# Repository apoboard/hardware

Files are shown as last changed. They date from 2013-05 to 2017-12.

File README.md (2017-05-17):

hardware
========

This Repo contains EAGLE CAD files for the DIY Interactive Electronics Apogaea PCB.

2013-14 Sound-reactive Sheriff Star
=======================================
<p align="center">

</p>

The system is based on an Atmega328p microcontroller (the same device in the Arduino Uno) and can be programmed with an FTDI serial adapter and the Arduino IDE. There is a DC/DC boost-converter to provide 5 volts from a single AA battery to a microphone, amplifier, and 3 RGB LEDs that are driven from common PWM channels. There is also a momentary tactile button for user input.

2017 Propagand-Eye
=======================================
<p align="center">

</p>

This board uses an Atmega328p microcontroller (the same device in the Arduino Uno) and can be programmed with an FTDI serial adapter and the Arduino IDE. There is a DC/DC boost-converter (the PAM2401) to provide 5 volts from a single AA battery. On board are 10 addressable WS2812 LEDs (the same LEDs used on all Neopixel products). There is also an infrared (IR) transmitter/receiver pair that allows the boards to communicate with one another. A tactile button is also provided to switch through modes.

License Information
-------------------

All of these files are developed for free, for Apogaea, and for fun. It is publicly available under the GNU General Public License version 2 (the "GPL License"). For more information, please see: http://www.gnu.org/licenses/gpl-2.0.html

Copyright (c) John English, Joel Bartlett, 2017 Licensing: GPL v2

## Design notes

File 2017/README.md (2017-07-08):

2017 Propagand-Eye
=======================================
<p align="center">

</p>

This board uses an Atmega328p microcontroller (the same device in the Arduino Uno) and can be programmed with an FTDI serial adapter and the Arduino IDE. There is a DC/DC boost-converter (the PAM2401) to provide 5 volts from a single AA battery. On board are 10 addressable WS2812 LEDs (the same LEDs used on all Neopixel products). There is also an infrared (IR) transmitter/receiver pair that allows the boards to communicate with one another. A tactile button is also provided to switch through modes.

Hacking Your Eyeball
=======================================
This section will cover all the information you'll need to start hacking your eye via hardware.

Arduino IDE Settings
----------------------
* Arduino IDE Version - 1.6.8
* Board - Arduino Uno
* Baud Rate - 115200

Hardware Pin connections
------------------
* Button Pin - D2
* WS2812 LED Pin - D7
* IR_RX Pin - D8
* IR_TX Pin - D9

Assembly Instructions
-------------------
<p align="center">

</p>

See the [Software README](https://github.com/apoboard/software/blob/master/2017/README.md) for more info. 

License Information
-------------------

All of these files are developed for free, for Apogaea, and for fun. It is publicly available under the GNU General Public License version 2 (the "GPL License"). For more information, please see: http://www.gnu.org/licenses/gpl-2.0.html

Copyright (c) John English, Joel Bartlett, 2017 Licensing: GPL v2

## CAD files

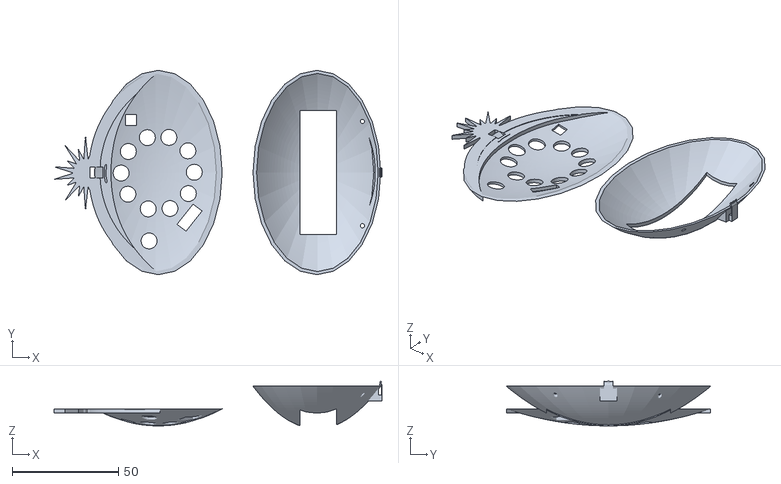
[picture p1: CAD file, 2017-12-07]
2017/3D Files/PropogandEye case.stl
154.1 x 96.0 x 21.0

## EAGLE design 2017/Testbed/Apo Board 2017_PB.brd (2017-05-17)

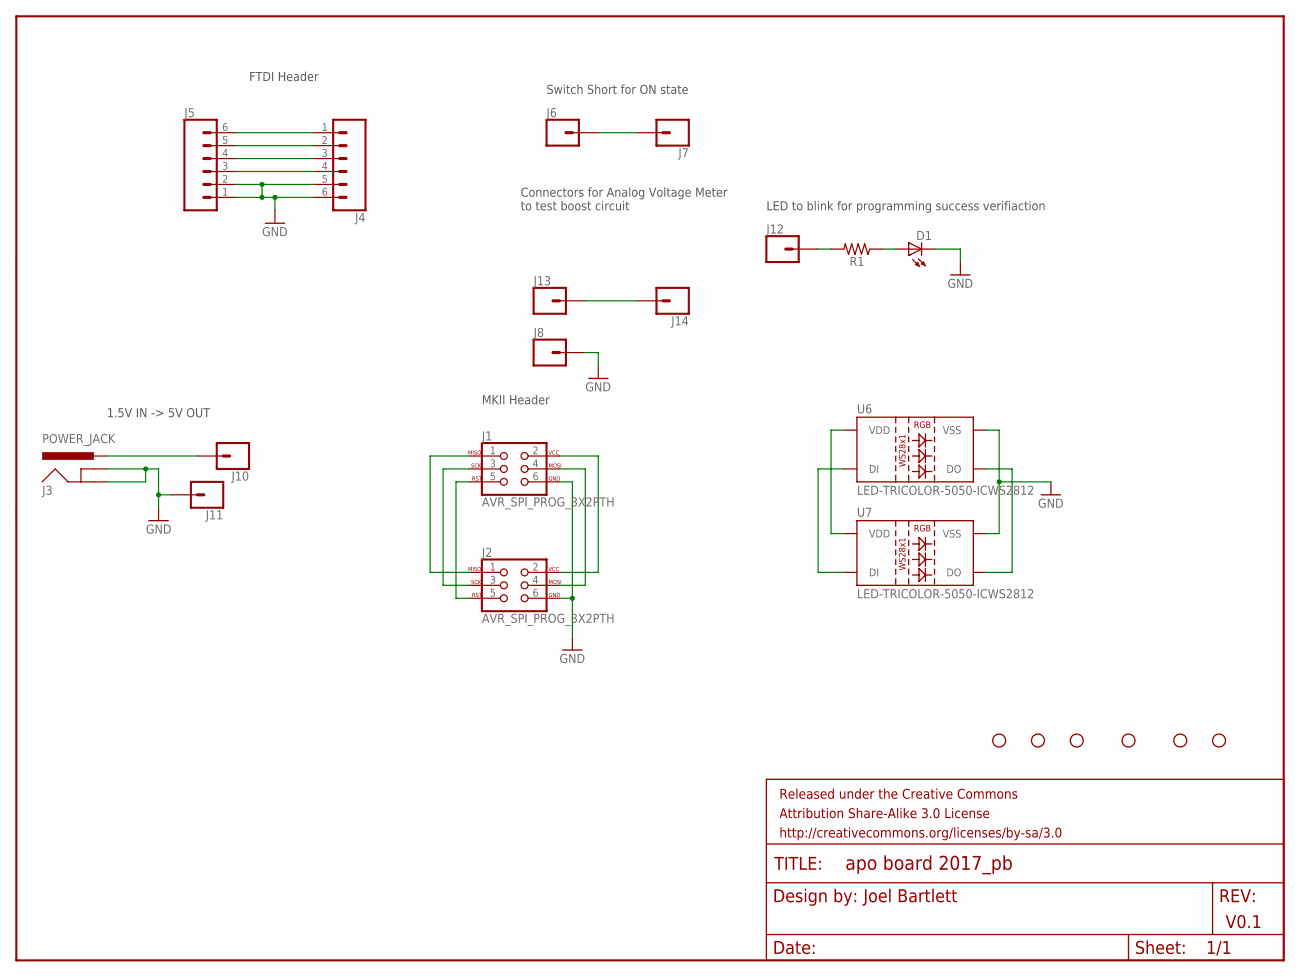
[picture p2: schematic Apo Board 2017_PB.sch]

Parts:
D1: LED5MM
FRAME1: FRAME-LETTER; CREATIVE_COMMONS
H1, H2, H3, H4, H5, H6: STAND-OFF
J1, J2: AVR_SPI_PROG_3X2PTH; 2X3
J3: POWER_JACK; POWER_JACK_PTH
J4, J5: CONN_06LONGPADS; 1X06_LONGPADS
J6, J7, J8, J10, J11, J12, J13, J14: CONN_01PTH_LONGPAD; 1X01_LONGPAD
R1: AXIAL-0.3-KIT
U6, U7: LED-TRICOLOR-5050-ICWS2812; LED-WS2812-THRU

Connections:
GND: D1.K (C), J1.6, J2.6, J3.GND, J3.GNDBREAK, J4.5, J4.6, J5.1, J5.2, J8.1, J11.1, U6.3 (VSS), U7.3 (VSS)
unnamed: J3.PWR, J10.1
unnamed: J1.4, J2.4
unnamed: J1.2, J2.2
unnamed: J1.5, J2.5
unnamed: J1.3, J2.3
unnamed: J1.1, J2.1
unnamed: U6.4 (DO), U7.4 (DO)
unnamed: J4.4, J5.3
unnamed: J4.3, J5.4
unnamed: J4.2, J5.5
unnamed: J4.1, J5.6
unnamed: J6.1, J7.1
unnamed: D1.A, R1.P$1 (1)
unnamed: J12.1, R1.P$2 (2)
unnamed: U6.1 (DI), U7.1 (DI)
unnamed: J13.1, J14.1
unnamed: U6.2 (VDD), U7.2 (VDD)

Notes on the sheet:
Joel Bartlett
V0.1
Switch Short for ON state
FTDI Header
1.5V IN -> 5V OUT
MKII Header
Connectors for Analog Voltage Meter to test boost circuit
LED to blink for programming success verifiaction

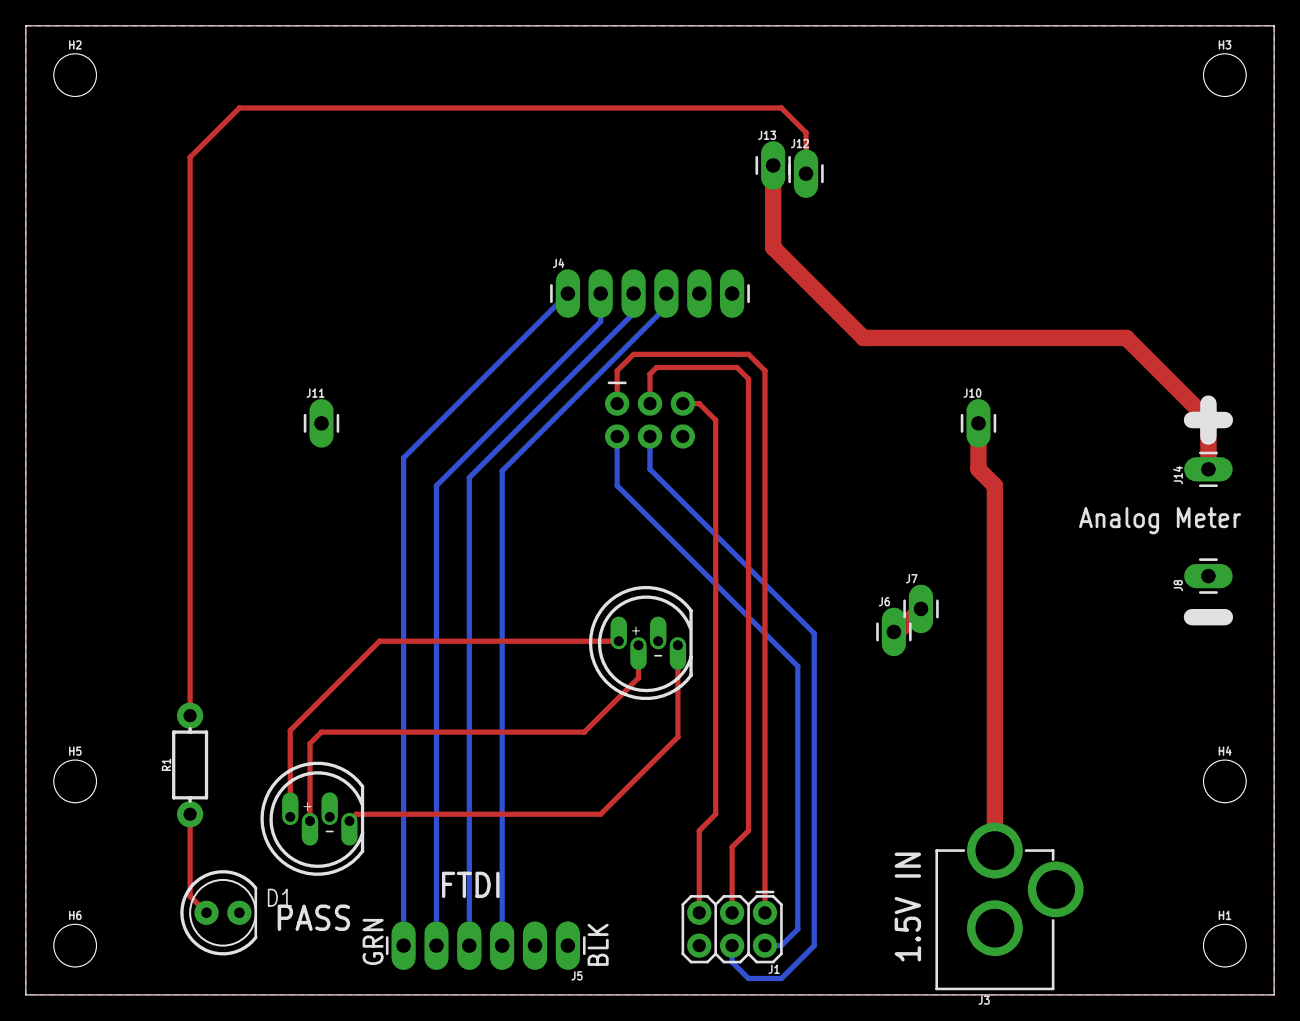
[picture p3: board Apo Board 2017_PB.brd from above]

Board: 2 copper layers, 96.5 x 74.9 mm, 24 parts (1 on the bottom side), 18 nets.

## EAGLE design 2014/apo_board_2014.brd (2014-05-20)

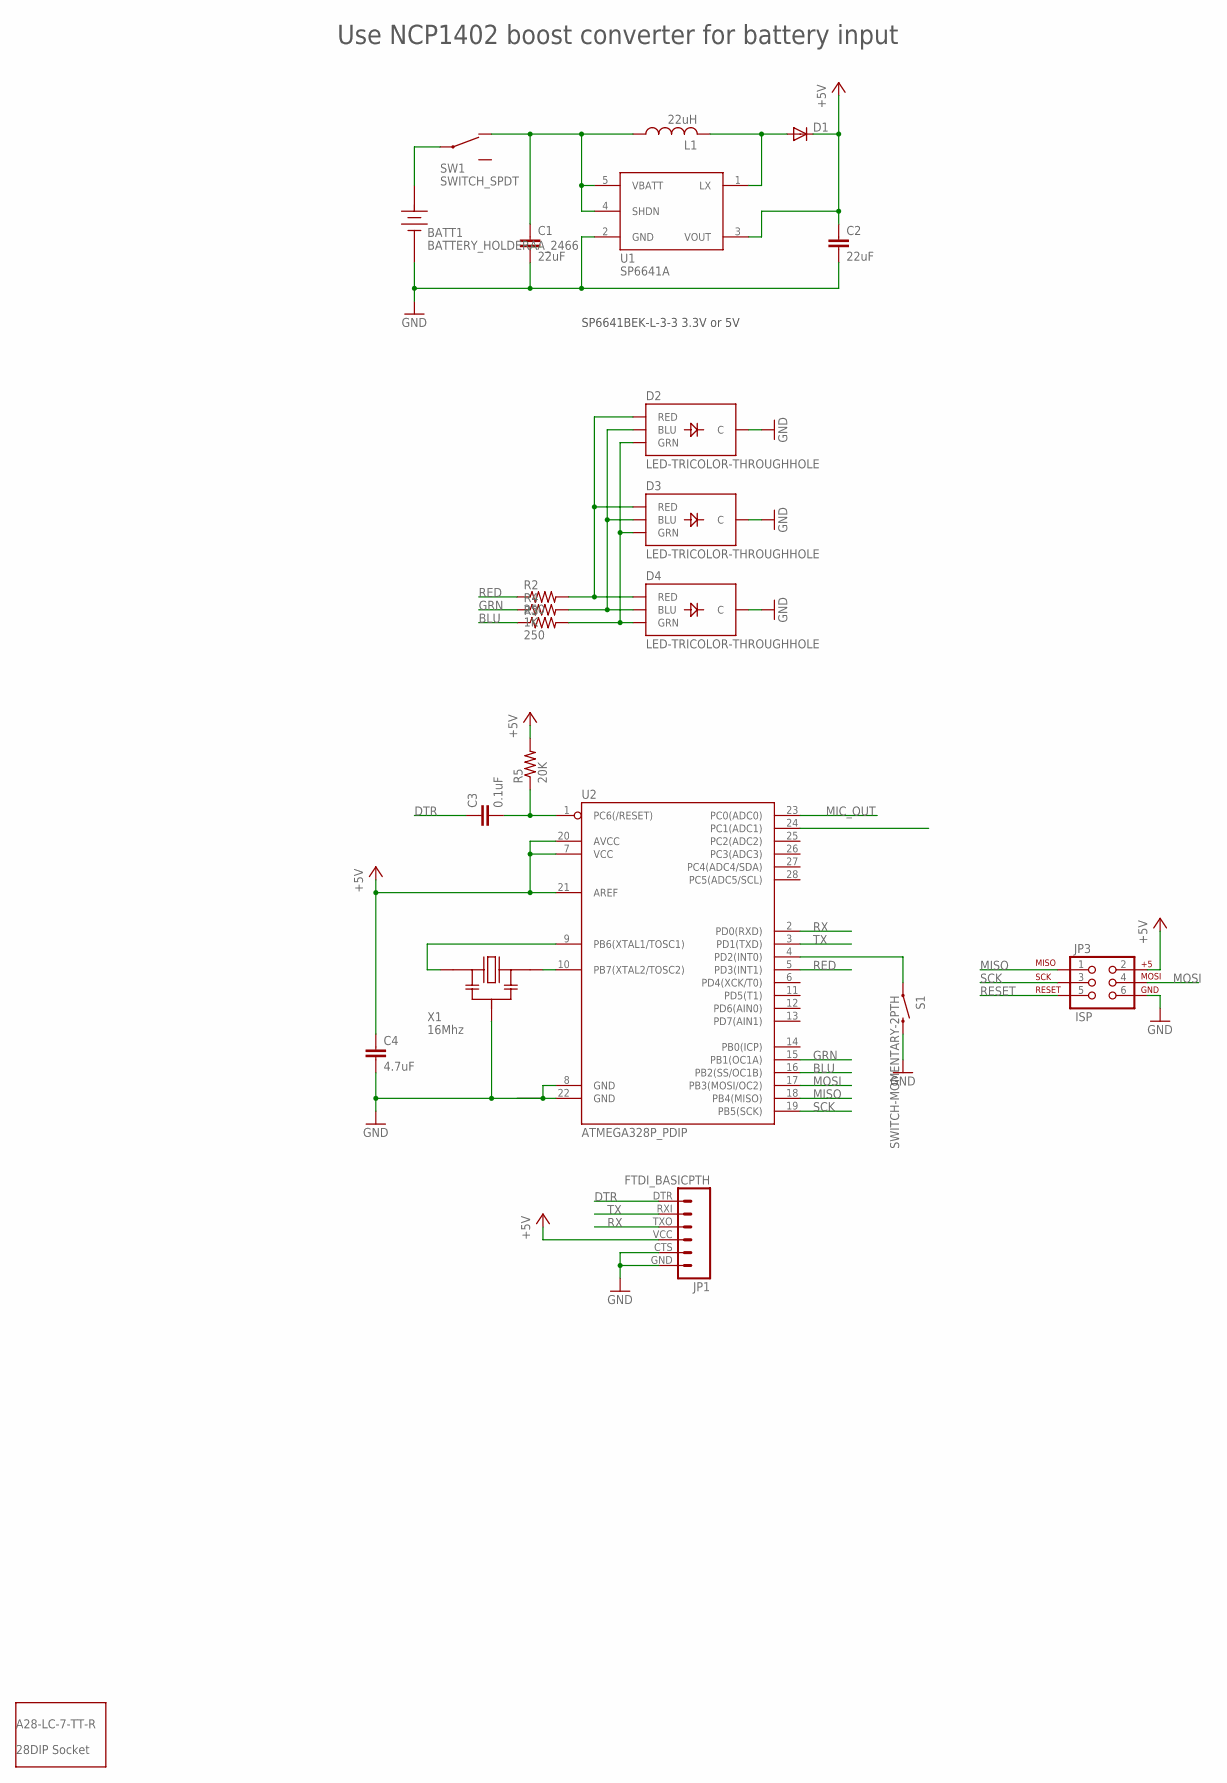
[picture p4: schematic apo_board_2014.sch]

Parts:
BATT1: BATTERY_HOLDERAA_2466; BATT_HOLDER_AA_2466
C1, C2: 22uF; CAP-PTH-SMALL-KIT
C3: 0.1uF; CAP-PTH-SMALL-KIT
C4: 4.7uF; CAP-PTH-SMALL-KIT
D1: DIODEKIT; DIODE-1N4148-KIT
D2, D3, D4: LED-TRICOLOR-THROUGHHOLE
JP1: FTDI_BASICPTH; FTDI_BASIC
JP3: ISP; 2X3
L1: 22uH; INDUCTOR_AIUR-02H
R2, R3: 250; AXIAL-0.3-KIT
R4: 1K; AXIAL-0.3-KIT
R5: 20K; AXIAL-0.3-KIT
S1: SWITCH-MOMENTARY-2PTH; TACTILE-PTH
SW1: SWITCH_SPDT; SWITCH_SPDT_OS102011MA1QN1C
U1: SP6641A; SOT23-5
U2: ATMEGA328P_PDIP; DIL28-3
X1: 16Mhz; CERAMIC_RESONATOR_ZTT

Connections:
+5V: C2.1, C4.1, D1.C, JP1.VCC (4), JP3.2, R5.P$2 (2), U1.3 (VOUT), U2.7 (VCC), U2.20 (AVCC), U2.21 (AREF)
BATT: BATT1.P, SW1.P$2 (COMMON)
BLU: R3.P$1 (1), U2.16 (PB2(SS/OC1B))
DTR: C3.1, JP1.DTR (1)
GND: BATT1.N, C1.2, C2.2, C4.2, D2.GND (C), D3.GND (C), D4.GND (C), JP1.CTS (5), JP1.GND (6), JP3.6, S1.3 (2), U1.2 (GND), U2.8 (GND), U2.22 (GND), X1.P$2
GRN: R4.P$1 (1), U2.15 (PB1(OC1A))
MIC_OUT: U2.23 (PC0(ADC0))
MISO: JP3.1, U2.18 (PB4(MISO))
MOSI: JP3.4, U2.17 (PB3(MOSI/OC2))
unnamed: U2.9 (PB6(XTAL1/TOSC1)), X1.P$1
unnamed: U2.10 (PB7(XTAL2/TOSC2)), X1.P$3
unnamed: S1.1, U2.4 (PD2(INT0))
unnamed: D2.GRN, D3.GRN, D4.GRN, R3.P$2 (2)
unnamed: D2.BLU, D3.BLU, D4.BLU, R4.P$2 (2)
unnamed: C3.2, R5.P$1 (1), U2.1 (PC6(/RESET))
unnamed: D2.RED, D3.RED, D4.RED, R2.P$2 (2)
unnamed: D1.A, L1.P$2 (2), U1.1 (LX)
unnamed: C1.1, L1.P$1 (1), SW1.P$3 (3), U1.4 (SHDN), U1.5 (VBATT)
RED: R2.P$1 (1), U2.5 (PD3(INT1))
RESET: JP3.5
RX: JP1.TXO (3), U2.2 (PD0(RXD))
SCK: JP3.3, U2.19 (PB5(SCK))
TX: JP1.RXI (2), U2.3 (PD1(TXD))

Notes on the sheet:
Use NCP1402 boost converter for battery input
SP6641BEK-L-3-3 3.3V or 5V

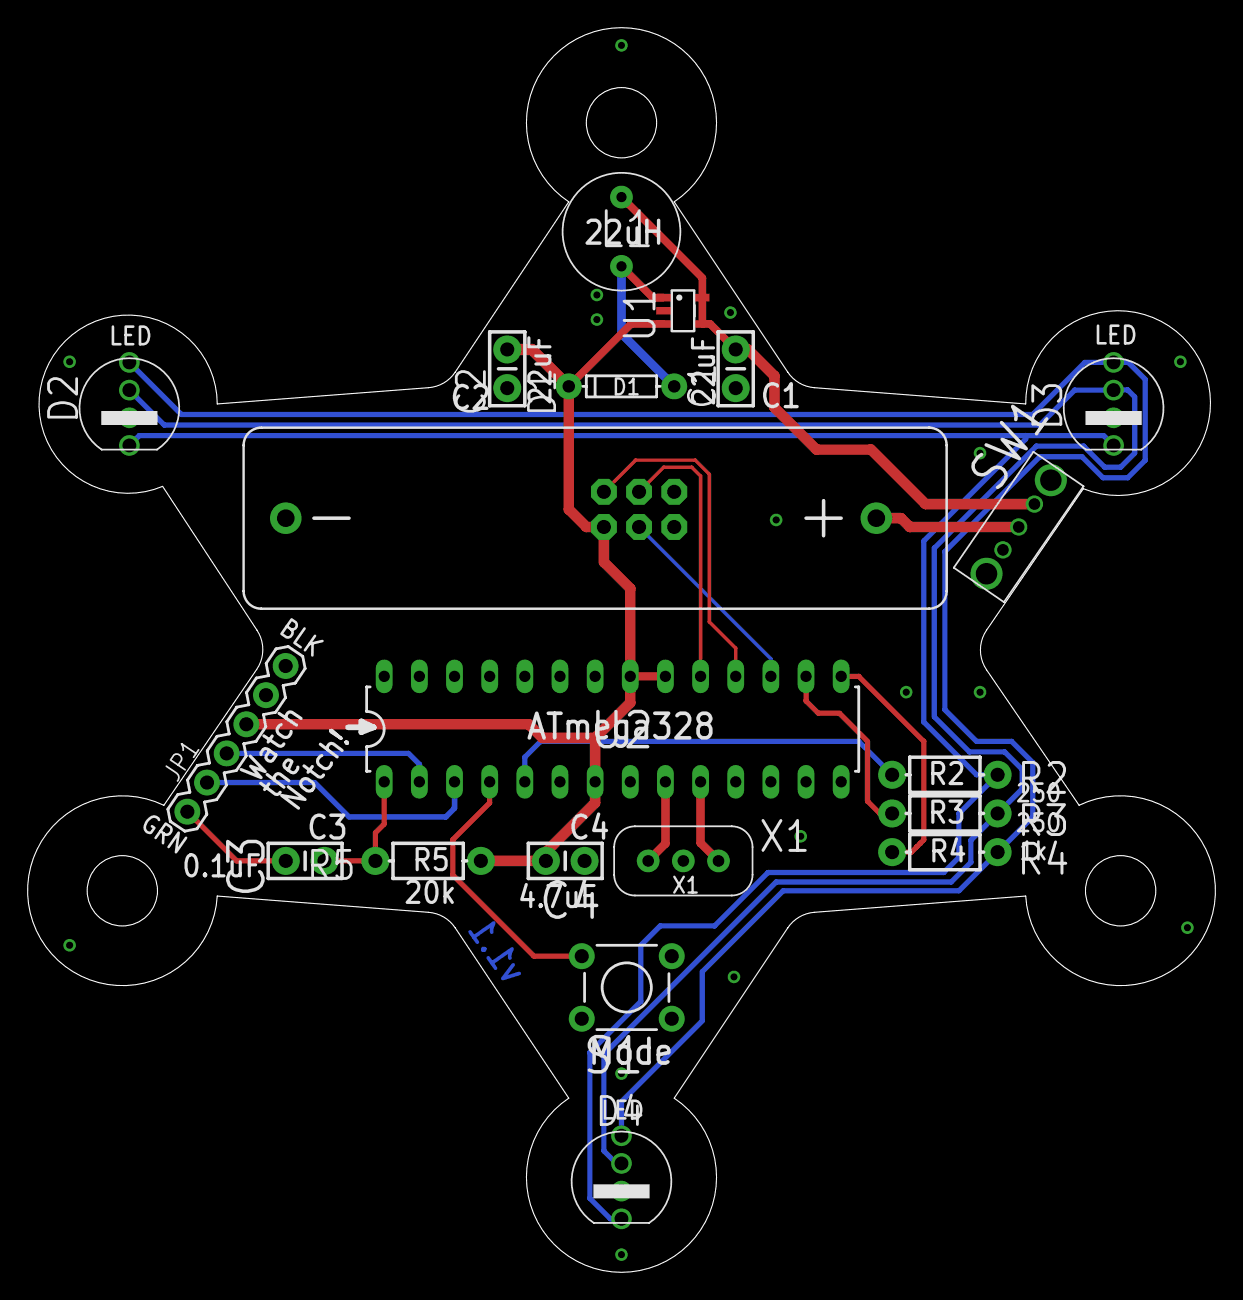
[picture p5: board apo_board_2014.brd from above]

Board: 2 copper layers, 85.8 x 89.9 mm, 21 parts (1 on the bottom side), 21 nets.

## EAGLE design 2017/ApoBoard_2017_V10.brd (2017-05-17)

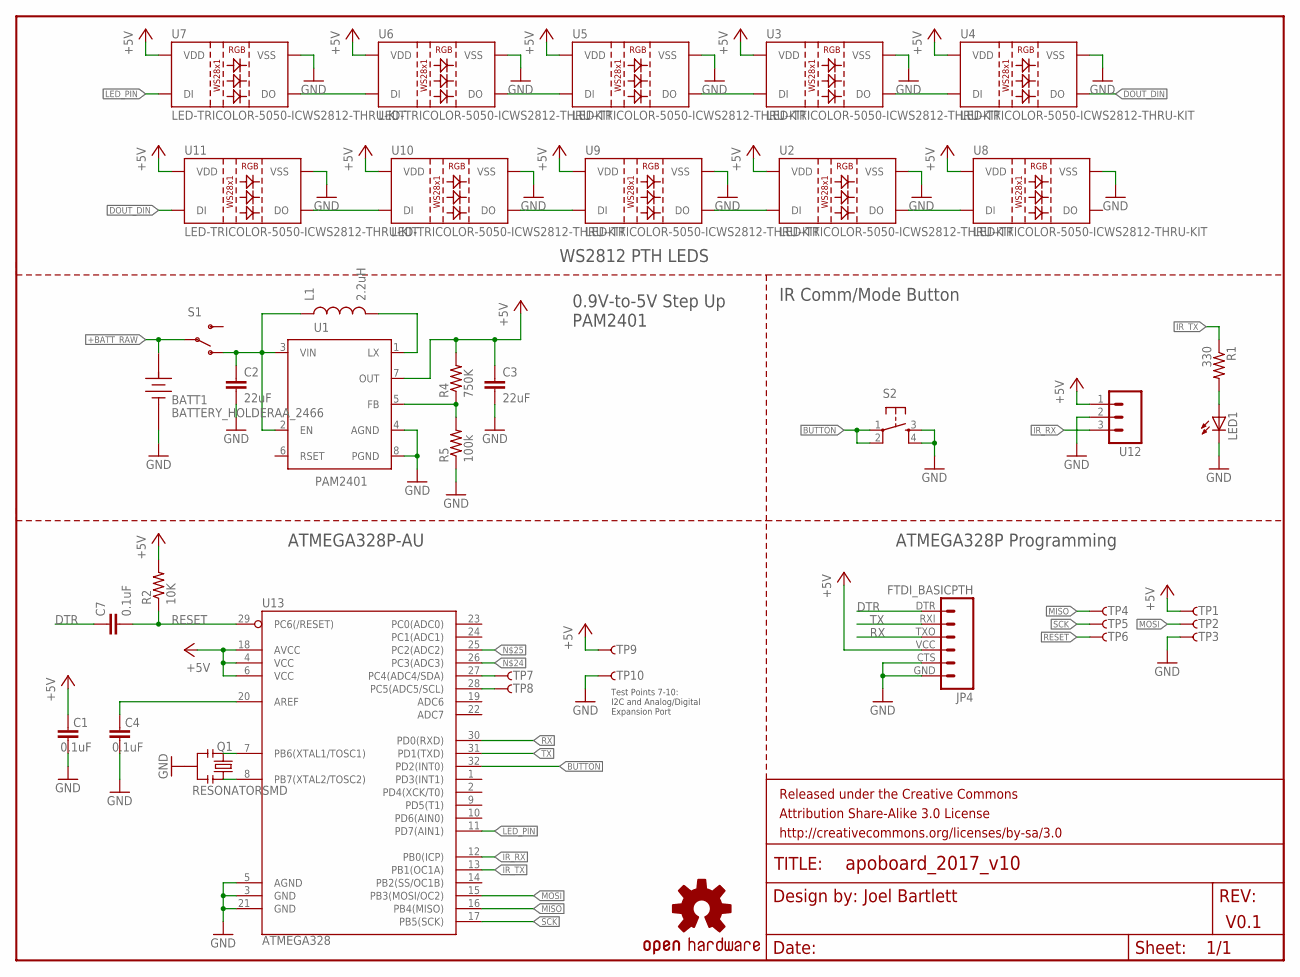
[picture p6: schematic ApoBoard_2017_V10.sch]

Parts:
BATT1: BATTERY_HOLDERAA_2466; BATT_HOLDER_AA_2466
C1, C4, C7: 0.1uF; 0402-CAP
C2, C3: 22uF; 0805
FRAME1: FRAME-LETTER; CREATIVE_COMMONS
JP4: FTDI_BASICPTH; FTDI_BASIC
L1: 2.2uH; CDRH2D09
LED1: LED5MM-KIT
LOGO1: OSHW-LOGOS; OSHW-LOGO-S
Q1: RESONATORSMD; RESONATOR-SMD
R1: 330; AXIAL-0.3-KIT
R2: 10K; 0402-RES
R4: 750K; 0603-RES
R5: 100k; 0603-RES
S1: SWITCH-SPSTKIT; SWITCH-SPDT_KIT
S2: TAC_SWITCHPTH; TACTILE-PTH
TP1, TP2, TP3, TP4, TP5, TP6, TP7, TP8, TP9, TP10: TP-3x5; PAD.03X.05
U1: PAM2401; MSOP8
U2, U3, U4, U5, U6, U7, U8, U9, U10, U11: LED-TRICOLOR-5050-ICWS2812-THRU-KIT; LED-RGB-THRU-KIT
U12: M03IR_RECEIVER; 1X03_IR_RECEIVER
U13: ATMEGA328; TQFP32-08

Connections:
+5V: C1.2, C3.1, JP4.VCC (4), R2.2, R4.2, TP1.P$1, TP9.P$1, U1.7 (OUT), U2.2 (VDD), U3.2 (VDD), U4.2 (VDD), U5.2 (VDD), U6.2 (VDD), U7.2 (VDD), U8.2 (VDD), U9.2 (VDD), U10.2 (VDD), U11.2 (VDD), U12.1, U13.4 (VCC), U13.6 (VCC), U13.18 (AVCC)
+BATT_RAW: BATT1.P, S1.2
AREF: C4.2, U13.20 (AREF)
BUTTON: S2.1, S2.2, U13.32 (PD2(INT0))
DOUT_DIN: U4.4 (DO), U11.1 (DI)
DTR: C7.1, JP4.DTR (1)
GND: BATT1.N, C1.1, C2.2, C3.2, C4.1, JP4.CTS (5), JP4.GND (6), LED1.K (C), Q1.2, R5.1, S2.3, S2.4, TP3.P$1, TP10.P$1, U1.4 (AGND), U1.8 (PGND), U2.3 (VSS), U3.3 (VSS), U4.3 (VSS), U5.3 (VSS), U6.3 (VSS), U7.3 (VSS), U8.3 (VSS), U9.3 (VSS), U10.3 (VSS), U11.3 (VSS), U12.2, U13.3 (GND), U13.5 (AGND), U13.21 (GND)
IR_RX: U12.3, U13.12 (PB0(ICP))
IR_TX: R1.P$1 (1), U13.13 (PB1(OC1A))
LED_PIN: U7.1 (DI), U13.11 (PD7(AIN1))
MISO: TP4.P$1, U13.16 (PB4(MISO))
MOSI: TP2.P$1, U13.15 (PB3(MOSI/OC2))
unnamed: U6.1 (DI), U7.4 (DO)
unnamed: U5.1 (DI), U6.4 (DO)
unnamed: LED1.A, R1.P$2 (2)
unnamed: TP7.P$1, U13.27 (PC4(ADC4/SDA))
unnamed: U3.1 (DI), U5.4 (DO)
unnamed: U3.4 (DO), U4.1 (DI)
unnamed: TP8.P$1, U13.28 (PC5(ADC5/SCL))
unnamed: L1.P$2 (2), U1.1 (LX)
unnamed: U10.1 (DI), U11.4 (DO)
unnamed: C2.1, L1.P$1 (1), S1.1 (O), U1.2 (EN), U1.3 (VIN)
unnamed: U9.1 (DI), U10.4 (DO)
unnamed: R4.1, R5.2, U1.5 (FB)
unnamed: U2.1 (DI), U9.4 (DO)
unnamed: U2.4 (DO), U8.1 (DI)
unnamed: Q1.1, U13.8 (PB7(XTAL2/TOSC2))
unnamed: Q1.3, U13.7 (PB6(XTAL1/TOSC1))
RESET: C7.2, R2.1, TP6.P$1, U13.29 (PC6(/RESET))
RX: JP4.TXO (3), U13.30 (PD0(RXD))
SCK: TP5.P$1, U13.17 (PB5(SCK))
TX: JP4.RXI (2), U13.31 (PD1(TXD))

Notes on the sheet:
Joel Bartlett
WS2812 PTH LEDS
0.9V-to-5V Step Up PAM2401
IR Comm/Mode Button
ATMEGA328P-AU
ATMEGA328P Programming
V0.1
Test Points 7-10: I2C and Analog/Digital Expansion Port

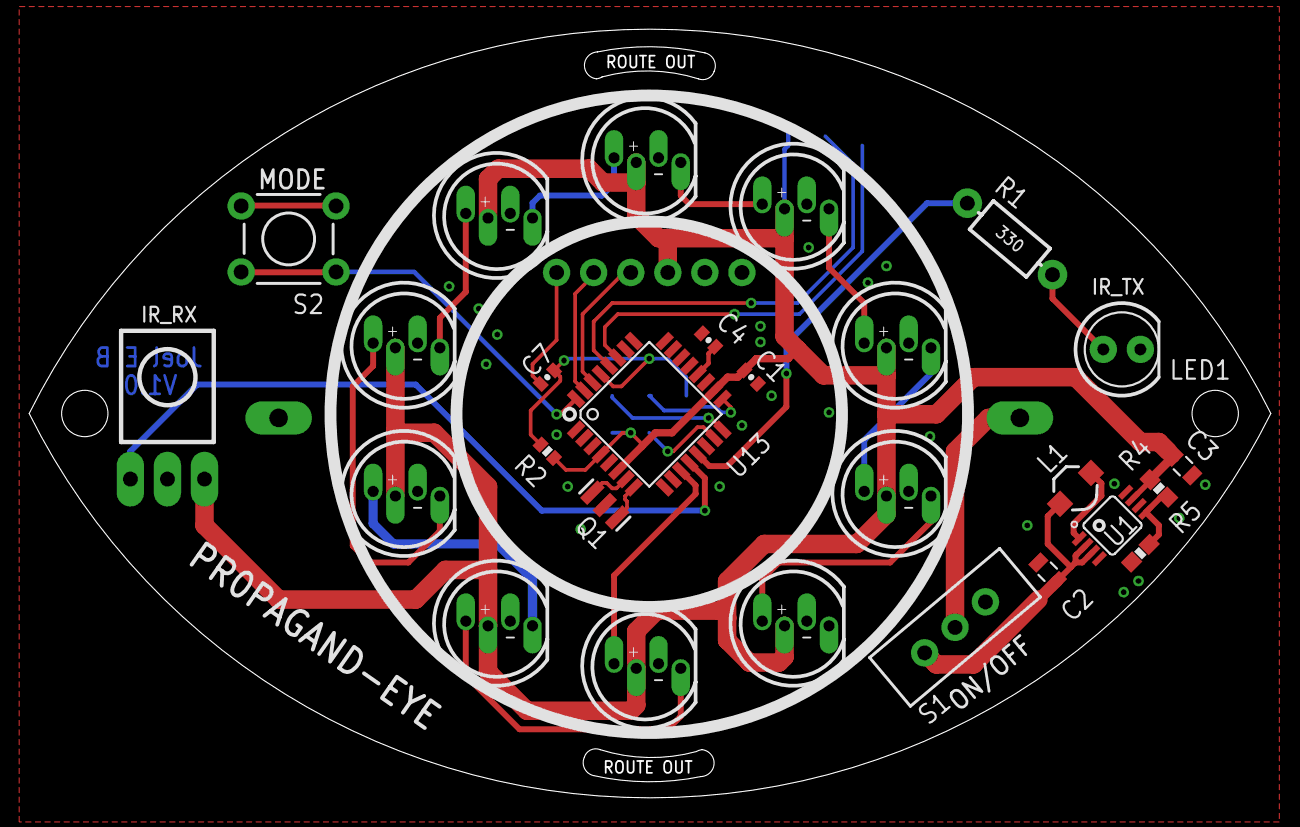
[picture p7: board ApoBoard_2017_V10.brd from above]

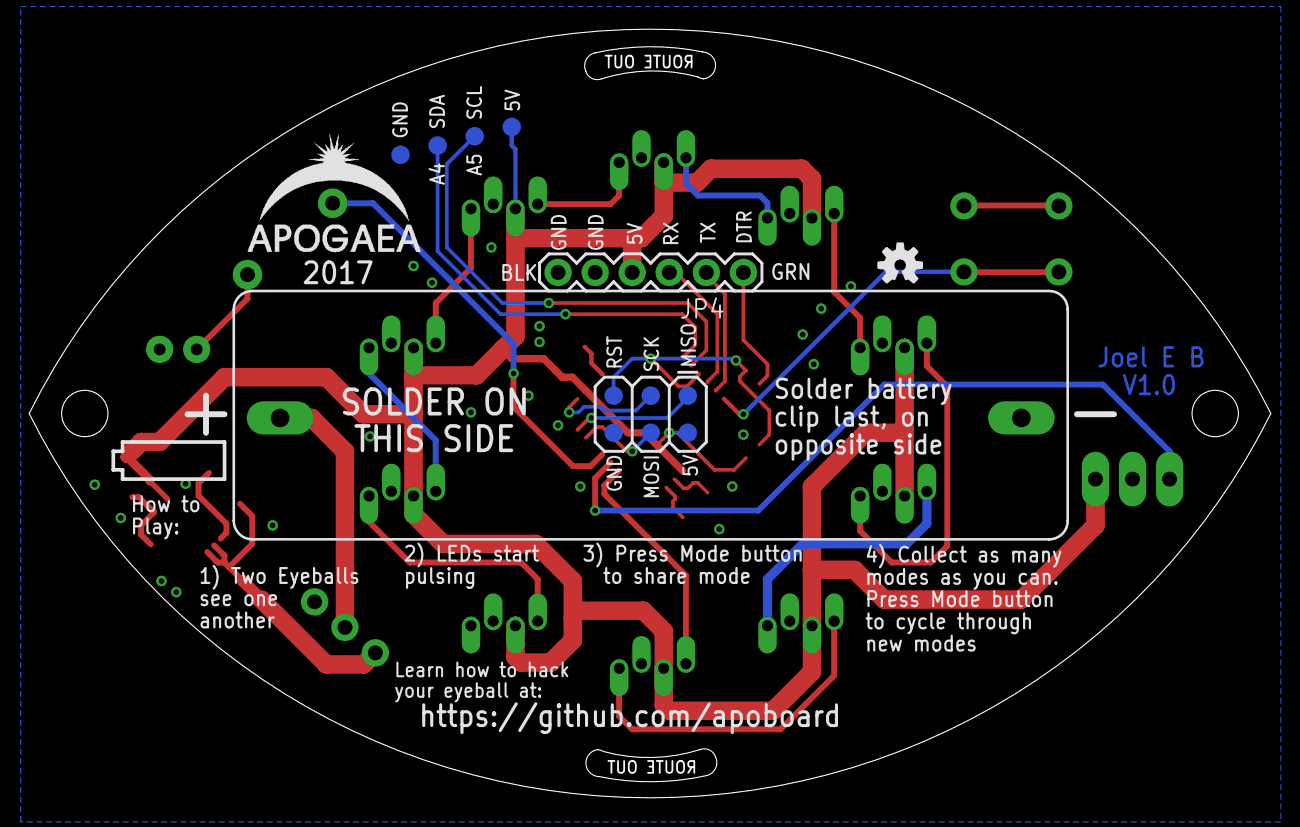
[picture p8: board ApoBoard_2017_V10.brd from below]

Board: 2 copper layers, 85.1 x 52.7 mm, 42 parts (14 on the bottom side), 32 nets.

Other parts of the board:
U$2: APOLOGO

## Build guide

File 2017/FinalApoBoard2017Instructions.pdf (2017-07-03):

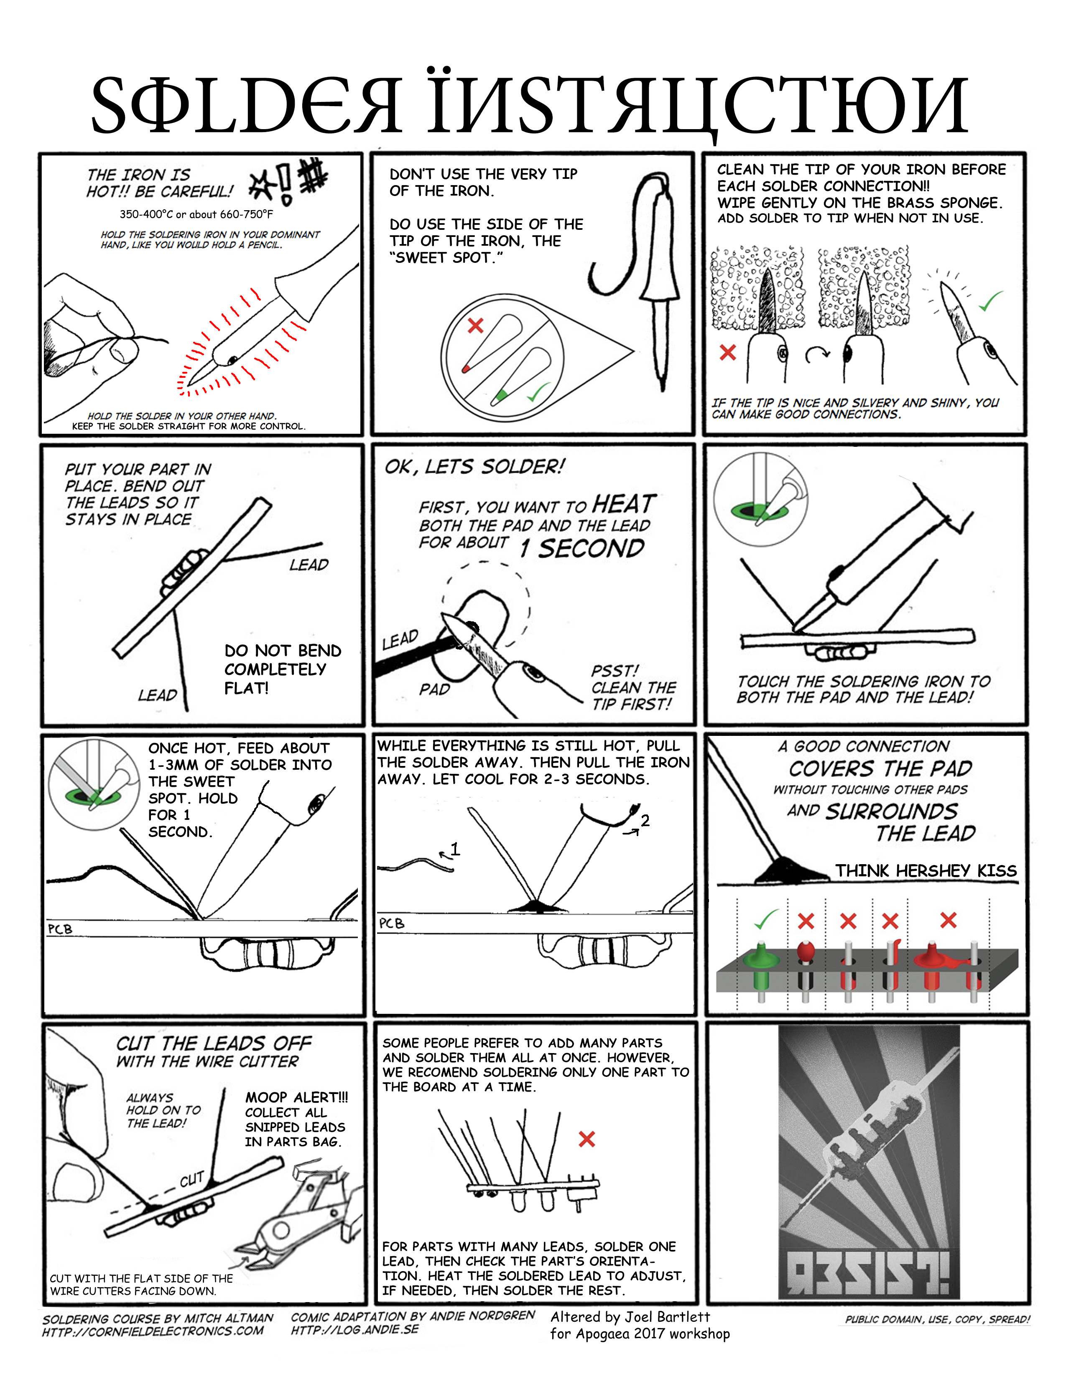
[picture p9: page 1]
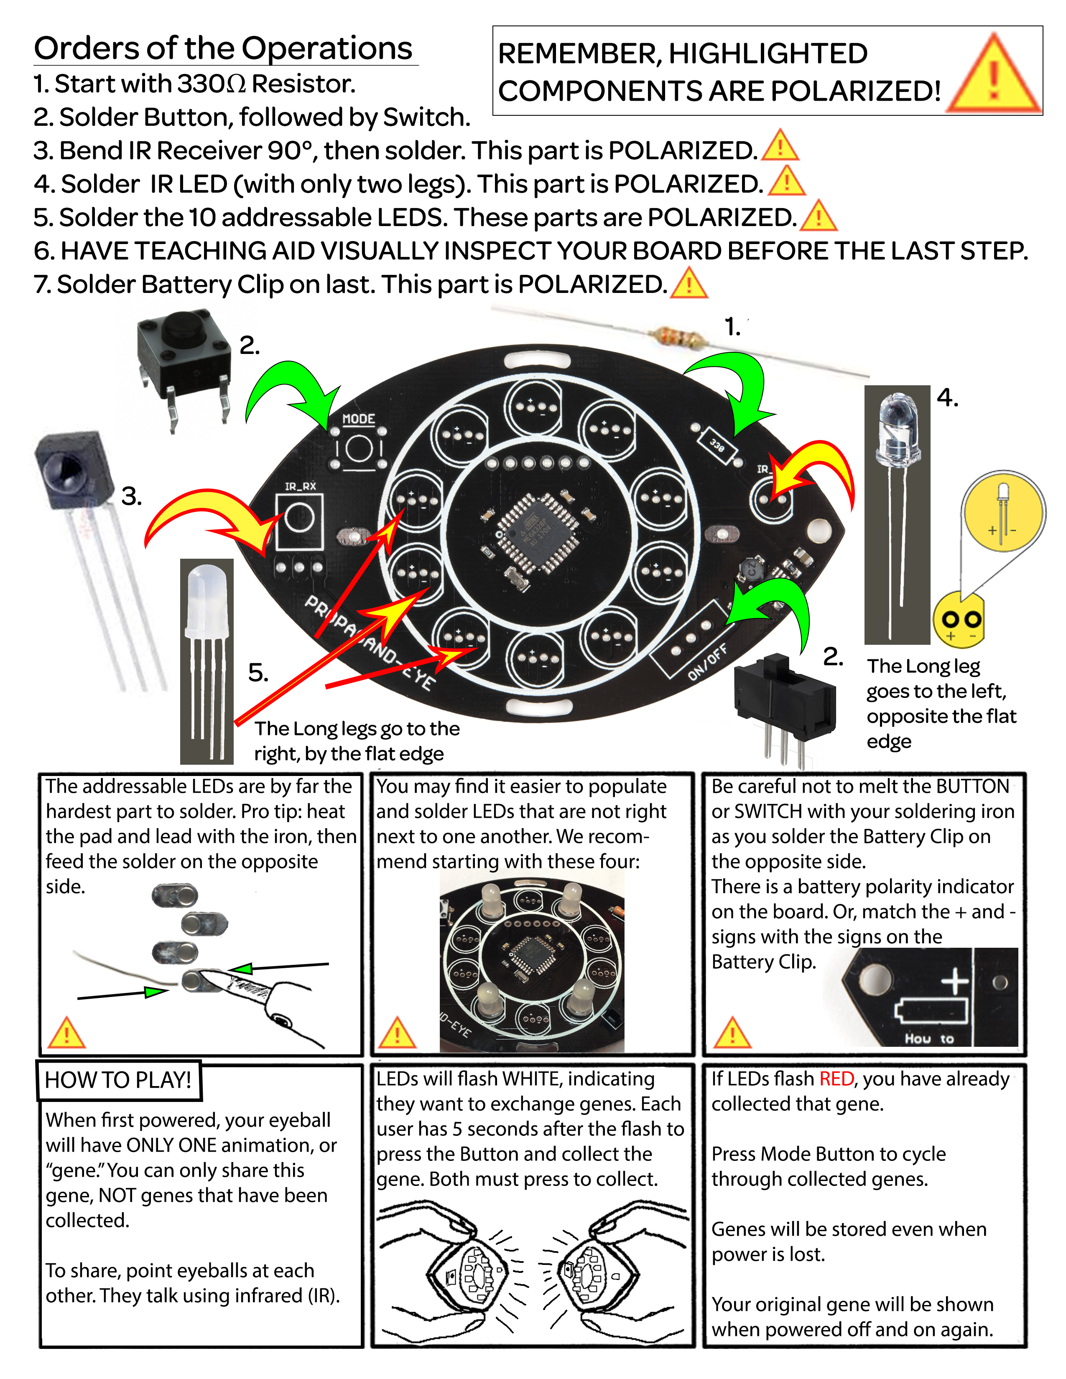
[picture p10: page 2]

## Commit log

2013-05-16 initial upload of Eagle CAD files for the DIY Apogaea PCB v0.1
    [apo_board.brd, apo_board.sch]
2014-05-20 Apogaea 2014 DIY electronics PCB eagle and gerber files, as ordered from Sunstone Circuits 2014-05-20
    [apo_board_2014.brd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]
2014-05-20 changed the name of the old board "apo_board_2013" to make it more obvious to people which is which
    [apo_board_2013.brd, apo_board_2013.sch]
2017-05-17 Adding 2017 hardware files
    [Apo Board 2017_PB.brd, Apo Board 2017_PB.sch, Apo Board 2017_PM.brd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]
2017-07-03 Adding final assembly instruction sheet
2017-12-07 Adding 3D Printable Enclosure
    Adding an STL file for a 3D printable enclosure for the Propaganda-Eye.
    Created by Jordan Shierstone
    [PropogandEye case.stl]

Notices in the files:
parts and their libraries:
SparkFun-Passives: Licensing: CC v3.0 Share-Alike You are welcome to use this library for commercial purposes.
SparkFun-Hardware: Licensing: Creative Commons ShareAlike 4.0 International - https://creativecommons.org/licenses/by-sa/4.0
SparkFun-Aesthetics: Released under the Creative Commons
